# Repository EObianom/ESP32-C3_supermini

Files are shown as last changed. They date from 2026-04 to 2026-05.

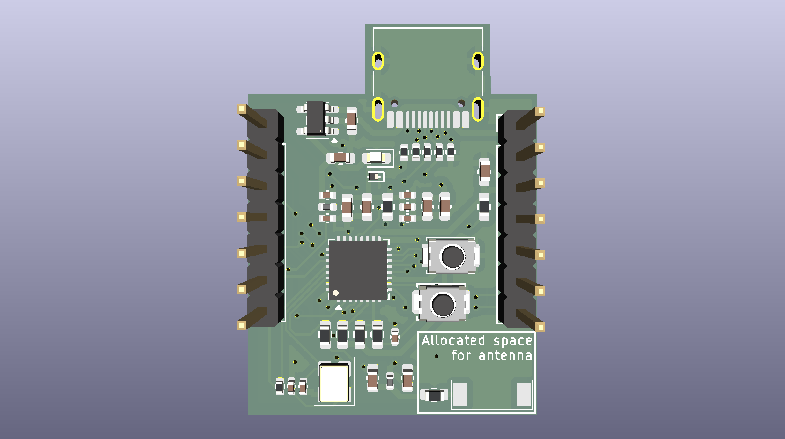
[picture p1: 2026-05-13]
ImageCopy.png

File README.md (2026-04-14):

# ESP32-C3_supermini

Ultra-Compact ESP32-C3 Development Board

A minimal, production-ready ESP32-C3 hardware design built from the bare chip, not a prepackaged module. Designed for engineers who prefer precision over excess.

Small footprint. Full capability. No shortcuts.



## Overview:

This project implements a highly compact ESP32-C3-based development board, designed from the ground up using the ESP32-C3 chip rather than a ready-made module. By eliminating unnecessary overhead and integrating a compact antenna based on manufacturer specifications, the design significantly reduces board size while maintaining reliable wireless performance.

The result is a lean, flexible, and fully manufacturable platform for embedded and IoT applications where space, control, and efficiency matter.

## Features:
- Ultra-compact PCB design (25mm × 27.8mm) optimised for space-constrained applications
- Built around the ESP32-C3 SoC (RISC-V architecture, Wi-Fi + Bluetooth LE)
- Uses a compact CA-C03 antenna based on manufacturer reference design
- No prebuilt module, full control over hardware design and layout
- Carefully designed RF layout for stable wireless performance
- USB interface for programming and power
- Low component count for cost-effective manufacturing
- Fully production-ready design files included

## Repository Contents
This repository provides a complete hardware package ready for fabrication and assembly:

1. Schematic
2. PCB Layout: Compact and optimised routing, including RF considerations
3. Footprints
4. Gerber Files: Ready-to-manufacture PCB fabrication files
5. BOM (JLC Format): Bill of Materials.
6. CPL File: Pick-and-place file for automated component assembly.

## Getting Started:
1. Review the schematic to understand system design and component choices
2. Open the PCB layout in KiCad to inspect placement and routing
3. Generate or use provided Gerber files to order your PCB
4. Upload the BOM and CPL files to JLCPCB (or similar) for assembly
5. Flash firmware via USB and begin development

Once assembled, the board can be programmed using standard ESP32-C3 toolchains such as ESP-IDF or Arduino.

## Applications:
- IoT devices
- Wearable electronics
- Embedded wireless systems
- Smart sensors and edge devices
- Custom ESP32-based product development

---
Disclaimer: This design is intended for research, development, and prototyping purposes only. Ensure proper RF compliance and certification before using in commercial products. This work is licensed under a Creative Commons Attribution-NonCommercial 4.0 International License.

Contributions and improvements are welcome. Feel free to open an issue or submit a pull request.

Designed and developed by Ekenedirichukwu Obianom

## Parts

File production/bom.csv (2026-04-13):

Designator | Footprint | Quantity | Value | LCSC Part #
AE1 | CA-C03_SMD_Antenna | 1 | Antenna
C1, C2 | 0402 | 2 | 18pF
C10, C12, C13, C16, C6, C7 | 0402 | 6 | 0.1uF
C11, C19, C20, C3 | 0603 | 4 | 1uF
C14, C5 | 0603 | 2 | 10uF
C4 | 0603 | 1 | 10nF
C8, C9 | 0603 | 2 | 1.6pF
D1 | D_SOD-923 | 1 | ESD9B3.3ST5G
D2 | 0603 | 1 | LED
J1, J2 | PinHeader_1x07_P2.54mm_Vertical | 2 | Conn_01x07_Pin
J3 | USB_C_Receptacle_HRO_TYPE-C-31-M-12 | 1 | USB_C_Receptacle_USB2.0_16P
L1, L2 | 0402 | 2 | 2.0nH
R1, R13, R6 | 0603 | 3 | 0
R10, R11 | 0402 | 2 | 22
R12 | 0402 | 1 | 220
R2 | 0402 | 1 | 499
R3, R4, R5, R7 | 0603 | 4 | 10K
R8, R9 | 0402 | 2 | 5.1K
SW1, SW2 | SW_Push_SPST_NO_Alps_SKRK | 2 | SW_Push
U1 | SOT-23-5 | 1 | ME6211C33M5
U2 | QFN-32-1EP_5x5mm_P0.5mm_EP3.7x3.7mm | 1 | ESP32-C3
Y1 | Crystal_SMD_3225-4Pin_3.2x2.5mm | 1 | Crystal_GND24_Small

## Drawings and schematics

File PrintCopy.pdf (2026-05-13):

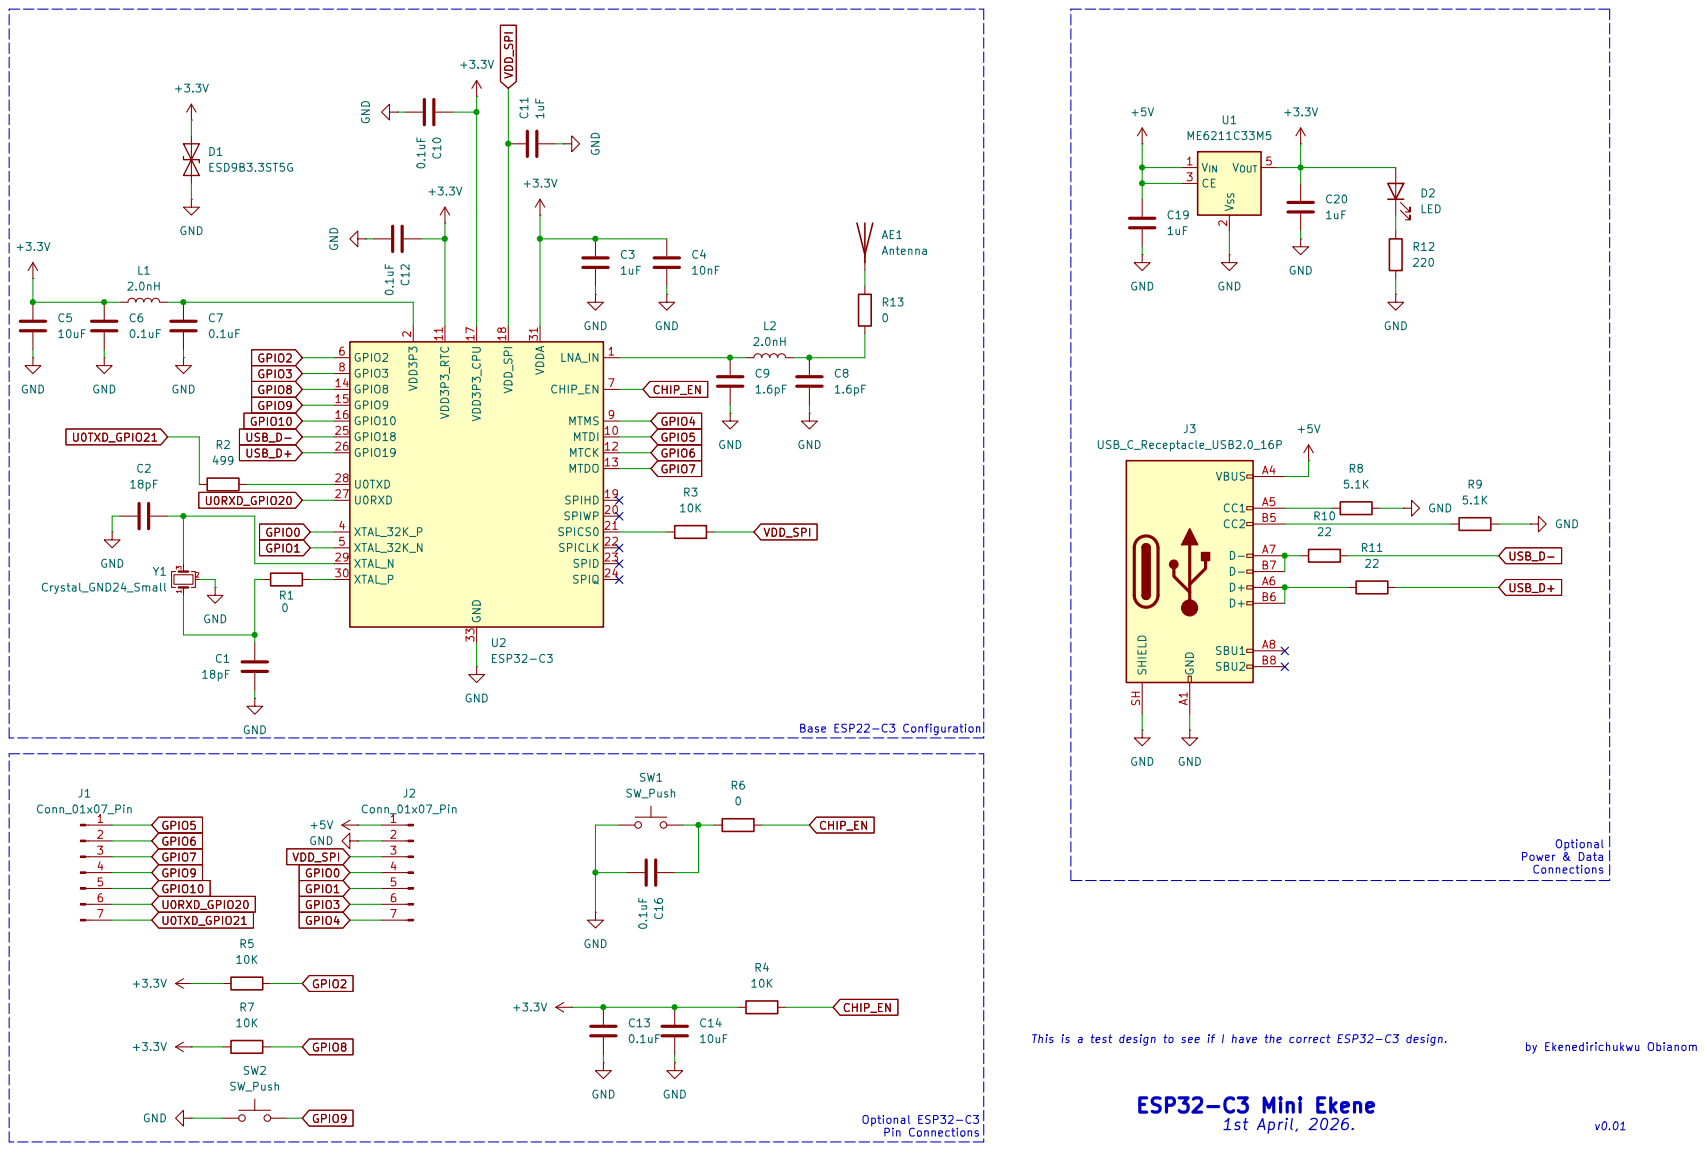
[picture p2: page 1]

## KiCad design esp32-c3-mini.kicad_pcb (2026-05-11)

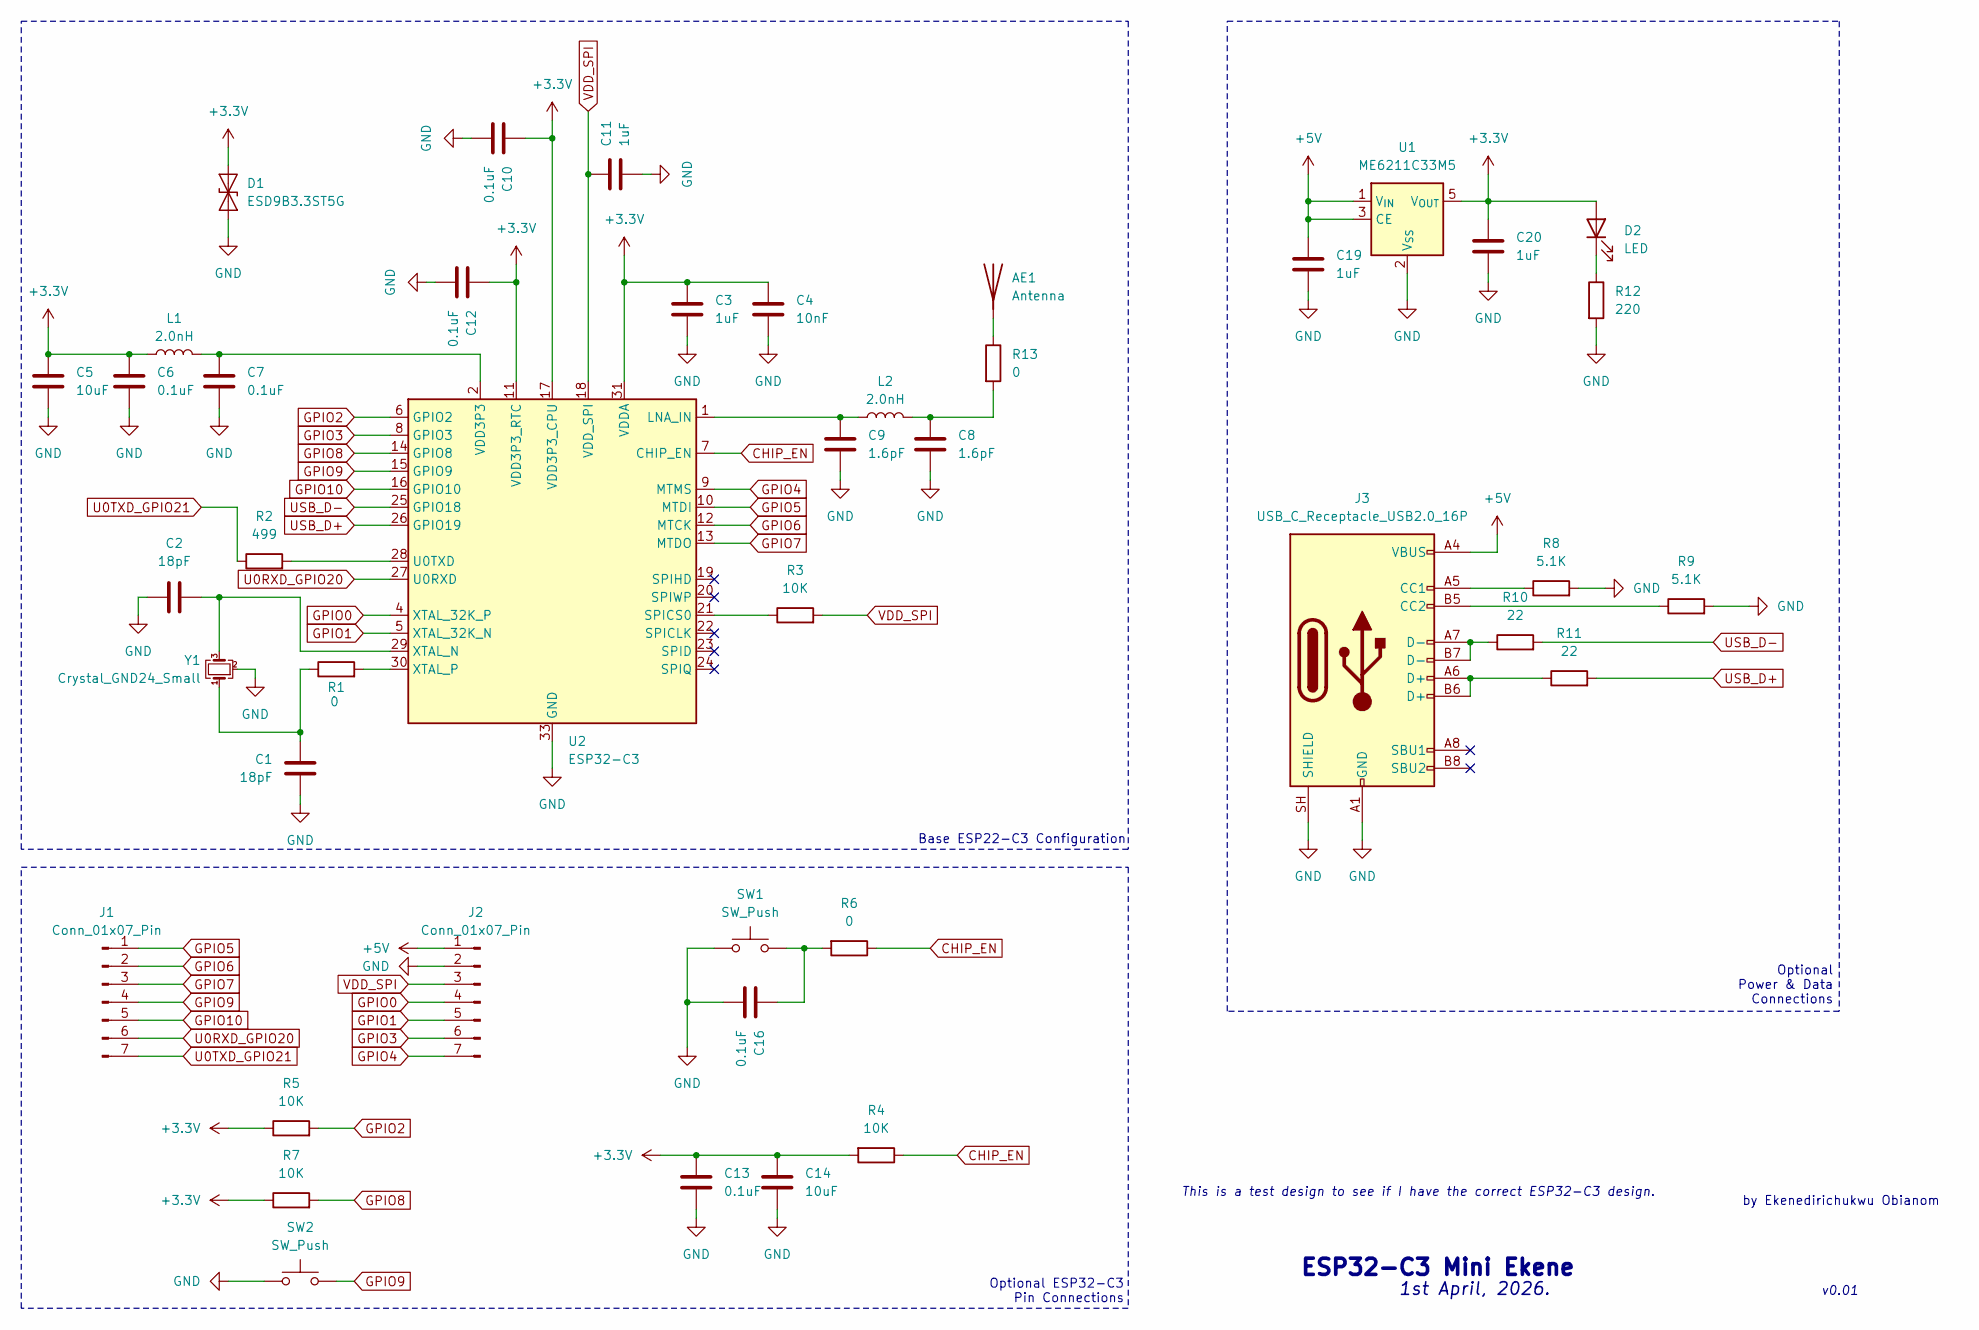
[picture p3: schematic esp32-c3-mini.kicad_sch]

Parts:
AE1: Antenna; CA-C03_SMD_Antenna
C1, C2: 18pF; C_0402_1005Metric
C3, C11, C19, C20: 1uF; C_0603_1608Metric
C4: 10nF; C_0603_1608Metric
C5, C14: 10uF; C_0603_1608Metric
C6, C7, C10, C12, C13, C16: 0.1uF; C_0402_1005Metric
C8, C9: 1.6pF; C_0603_1608Metric
D1: ESD9B3.3ST5G; D_SOD-923
D2: LED; LED_0603_1608Metric
J1, J2: Conn_01x07_Pin; PinHeader_1x07_P2.54mm_Vertical
J3: USB_C_Receptacle_USB2.0_16P; USB_C_Receptacle_HRO_TYPE-C-31-M-12
L1, L2: 2.0nH; L_0402_1005Metric
R1, R6, R13: 0; R_0603_1608Metric
R2: 499; R_0402_1005Metric
R3, R4, R5, R7: 10K; R_0603_1608Metric
R8, R9: 5.1K; R_0402_1005Metric
R10, R11: 22; R_0402_1005Metric
R12: 220; R_0402_1005Metric
SW1, SW2: SW_Push; SW_Push_SPST_NO_Alps_SKRK
U1: ME6211C33M5; SOT-23-5
U2: ESP32-C3; QFN-32-1EP_5x5mm_P0.5mm_EP3.7x3.7mm
Y1: Crystal_GND24_Small; Crystal_SMD_3225-4Pin_3.2x2.5mm

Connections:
+3.3V: C3.1, C4.1, C5.1, C6.1, C10.1, C12.1, C13.1, C14.1, C20.1, D1.2 (A2), D2.2 (A), L1.1, R4.2, R5.1, R7.1, U1.5 (V_{OUT}), U2.11 (VDD3P3_RTC), U2.17 (VDD3P3_CPU), U2.31 (VDDA), U2.32 (VDDA)
+5V: C19.1, J2.1, J3.A4 (VBUS), J3.A9 (VBUS), J3.B4 (VBUS), J3.B9 (VBUS), U1.1 (V_{IN}), U1.3 (CE)
CHIP_EN: R4.1, R6.1, U2.7 (CHIP_EN)
GND: C1.1, C2.2, C3.2, C4.2, C5.2, C6.2, C7.2, C8.2, C9.2, C10.2, C11.2, C12.2, C13.2, C14.2, C16.2, C19.2, C20.2, D1.1 (A1), J2.2, J3.A1 (GND), J3.A12 (GND), J3.B1 (GND), J3.B12 (GND), J3.SH (SHIELD), R8.2, R9.2, R12.2, SW1.1, SW2.1, U1.2 (V_{SS}), U2.33 (GND), Y1.2 (G), Y1.4 (G)
GPIO0: J2.4, U2.4 (XTAL_32K_P)
GPIO1: J2.5, U2.5 (XTAL_32K_N)
GPIO2: R5.2, U2.6 (GPIO2)
GPIO3: J2.6, U2.8 (GPIO3)
GPIO4: J2.7, U2.9 (MTMS)
GPIO5: J1.1, U2.10 (MTDI)
GPIO6: J1.2, U2.12 (MTCK)
GPIO7: J1.3, U2.13 (MTDO)
GPIO8: R7.2, U2.14 (GPIO8)
GPIO9: J1.4, SW2.2, U2.15 (GPIO9)
GPIO10: J1.5, U2.16 (GPIO10)
unnamed: AE1.1 (A_1), R13.1
unnamed: C1.2, R1.1, Y1.1
unnamed: C7.1, L1.2, U2.2 (VDD3P3), U2.3 (VDD3P3)
unnamed: C8.1, L2.1, R13.2
unnamed: C16.1, R6.2, SW1.2
unnamed: D2.1 (K), R12.1
unnamed: J3.A5 (CC1), R8.1
unnamed: J3.B5 (CC2), R9.1
unnamed: J3.A6 (D+), J3.B6 (D+), R11.1
unnamed: J3.A7 (D-), J3.B7 (D-), R10.1
unnamed: C9.1, L2.2, U2.1 (LNA_IN)
unnamed: R3.1, U2.21 (SPICS0)
unnamed: R2.2, U2.28 (U0TXD)
unnamed: C2.1, U2.29 (XTAL_N), Y1.3
unnamed: R1.2, U2.30 (XTAL_P)
U0RXD_GPIO20: J1.6, U2.27 (U0RXD)
U0TXD_GPIO21: J1.7, R2.1
USB_D+: R11.2, U2.26 (GPIO19)
USB_D-: R10.2, U2.25 (GPIO18)
VDD_SPI: C11.1, J2.3, R3.2, U2.18 (VDD_SPI)

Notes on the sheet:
Base ESP22-C3 Configuration
1st April, 2026.
This is a test design to see if I have the correct ESP32-C3 design.
Optional ESP32-C3 Pin Connections
v0.01
ESP32-C3 Mini Ekene
by Ekenedirichukwu Obianom
Optional Power & Data Connections

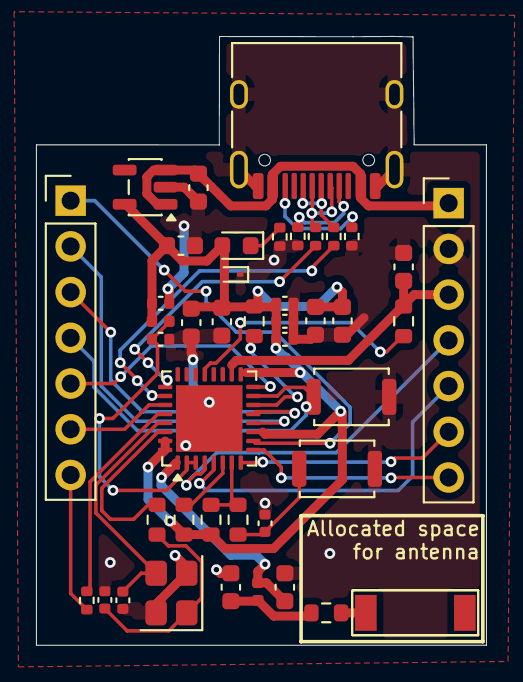
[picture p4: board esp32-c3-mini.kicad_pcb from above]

Board: 4 copper layers, 25.0 x 33.8 mm, 43 parts (0 on the bottom side), 35 nets.

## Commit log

2026-04-08 Add ESP32-C3 mini KiCad project and gerbers
    Add a new KiCad project for the ESP32-C3 Mini including project file (.kicad_pro), schematic (.kicad_sch), PCB (.kicad_pcb), and library entries (fp-lib-table and CA-C03_SMD_Antenna footprint). Also 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
    [esp32-c3-mini-B_Mask.gbr, esp32-c3-mini-B_Paste.gbr, esp32-c3-mini-B_Silkscreen.gbr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]
2026-04-08 Add image to README for ESP32-C3 supermini
2026-04-08 Enhance README with BOM and CPL file information
    Added BOM and CPL file details to the README and updated assembly instructions.
2026-04-08 Adjust solder mask and add production files
    Remove explicit solder_mask_min_width from PCB file and update project settings to set solder_mask_to_copper_clearance to 0.005. Add fabrication-toolkit-options.json and generated production artifact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
    [esp32-c3-mini.kicad_pcb]
2026-04-09 Add production BOM/designators/positions CSVs
    Add production artifacts for PCB assembly: production/bom.csv (bill of materials), production/designators.csv (component counts), and production/positions.csv (pick-and-place coordinates).
    Also update .gitignore to stop excluding exported BOM files (*.xml, *.csv) so these production CSVs can be committed. These files provide necessary data for procurement and assembly.
    [bom.csv, designators.csv, positions.csv]
2026-04-13 Replace USB plug with USB-C receptacle
    Replace the previous USB plug footprint with a USB_C_Receptacle_HRO_TYPE-C-31-M-12 footprint (USB2.0/PD). Update pad geometry, positions, orientations, silkscreen and UUIDs; remap nets/pin names from the old P2 plugin (P2-CC, P2-D+, P2-D-, P2-VCONN, etc.) to J3 equivalents and adjust pad sizes/types (SMD and thru-holes) accordingly. Remove generated Gerber outputs and add a production backup ZIP; update production artifacts (bom.csv, designators.csv, esp32-c3-mini.zip, netlist.ipc, positions.csv) to reflect the PCB changes.
    [bom.csv, designators.csv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]
2026-05-11 Rotate USB-C footprint and update routing
    Rotate the USB-C receptacle footprint 180° (update (at) coordinates and properties), mirror/update silkscreen/courtyard/fab lines and refresh fp UUIDs. Add/adjust board routing: new traces, vias and segments for CC1/CC2 and USB D+/D- nets, and reorganize GND and +5V segments (replace/relocate several vias and segments). Regenerate production artifacts: updated production zip, netlist and positions CSV, and add a production backup archive.
    [esp32-c3-mini.kicad_pcb, positions.csv]
2026-05-13 Add ImageCopy.png and PrintCopy.pdf
    Add two binary assets: ImageCopy.png and PrintCopy.pdf. These files provide image and printable PDF copies used by the project (added as new assets).
